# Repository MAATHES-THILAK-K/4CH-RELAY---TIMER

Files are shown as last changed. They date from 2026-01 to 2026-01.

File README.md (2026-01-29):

# 4CH Relay Timer

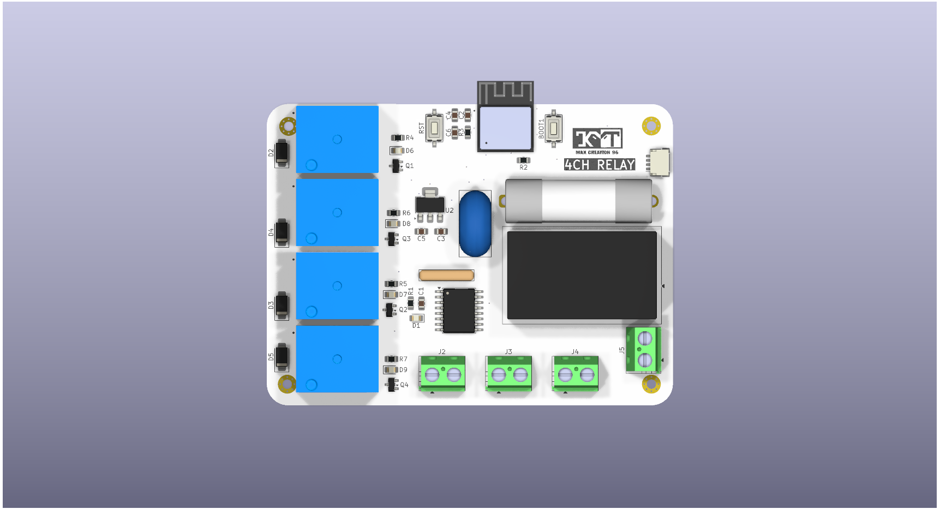
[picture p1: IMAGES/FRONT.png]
PCB


## Overview
ESP32-C3 based 4-channel relay controller with DS3231 RTC for timer applications. Each channel handles 10A AC loads with MOSFET input control.

## Features
- 4x 10A relays with MOSFET control
- ESP32-C3 Mini for Wi-Fi/Bluetooth
- DS3231 RTC for precise timing
- Direct AC input sensing
- Timer-based automation

## Hardware
- MCU: ESP32-C3-MINI-1
- RTC: DS3231 with battery backup
- Relays: 10A 250VAC SPDT
- Input: 5V DC
- AC sensing: Opto-isolated

## Usage
1. Power with 5V DC
2. Connect AC loads to relay outputs
3. Program via USB-C
4. Set timers via web interface

## Safety
⚠️ **HIGH VOLTAGE** - Requires proper insulation and qualified installation.

## License
Apache 2.0

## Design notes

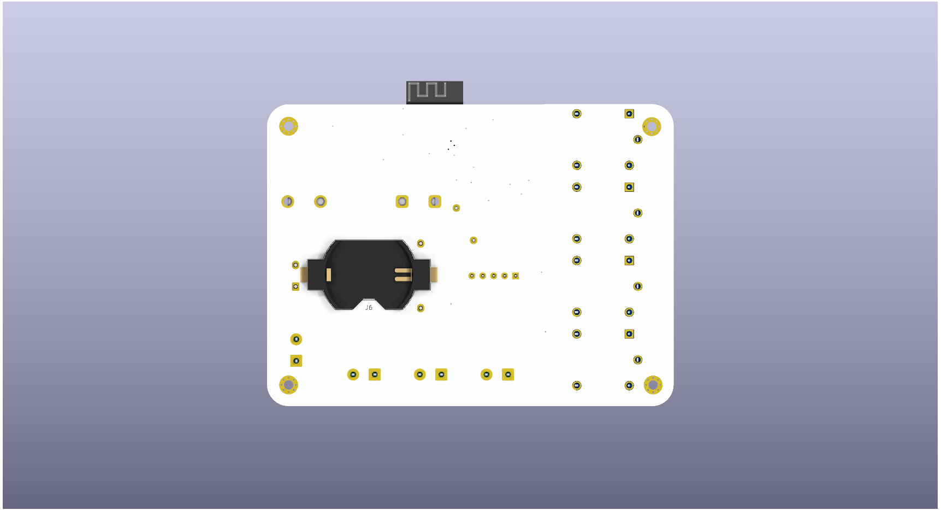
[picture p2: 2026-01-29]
IMAGES/BACK.png

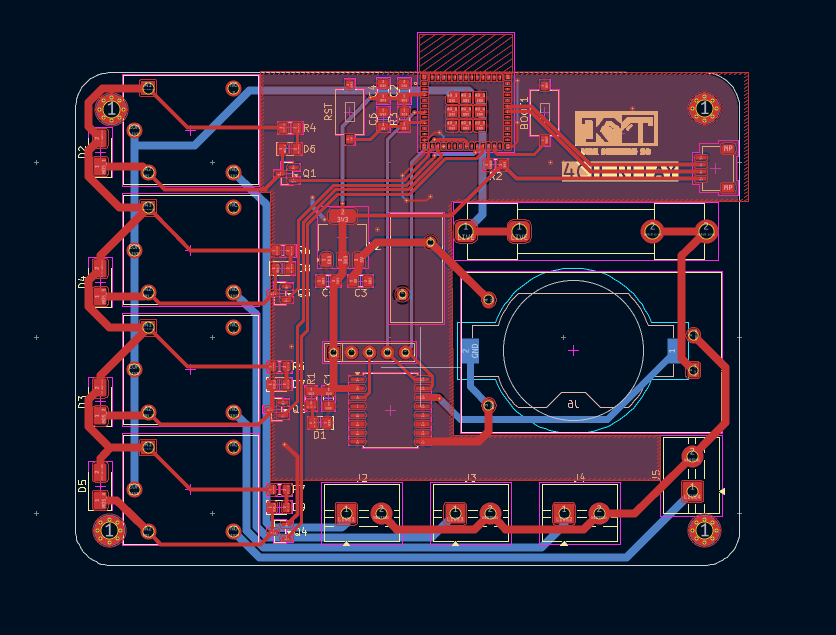
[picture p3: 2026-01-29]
IMAGES/Screenshot from 2026-01-29 18-53-19.png

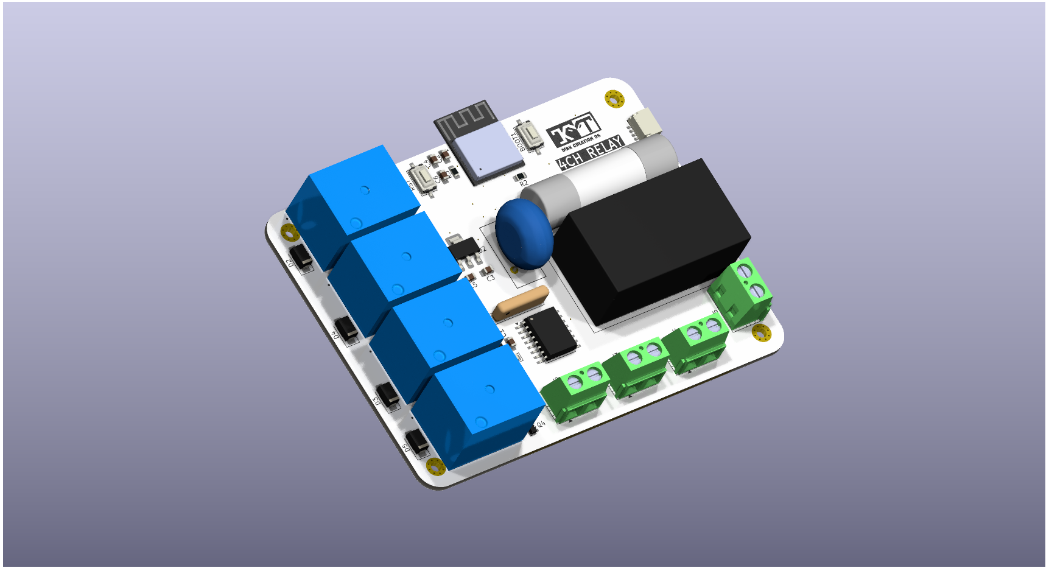
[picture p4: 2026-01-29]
IMAGES/ISOMETRIC.png

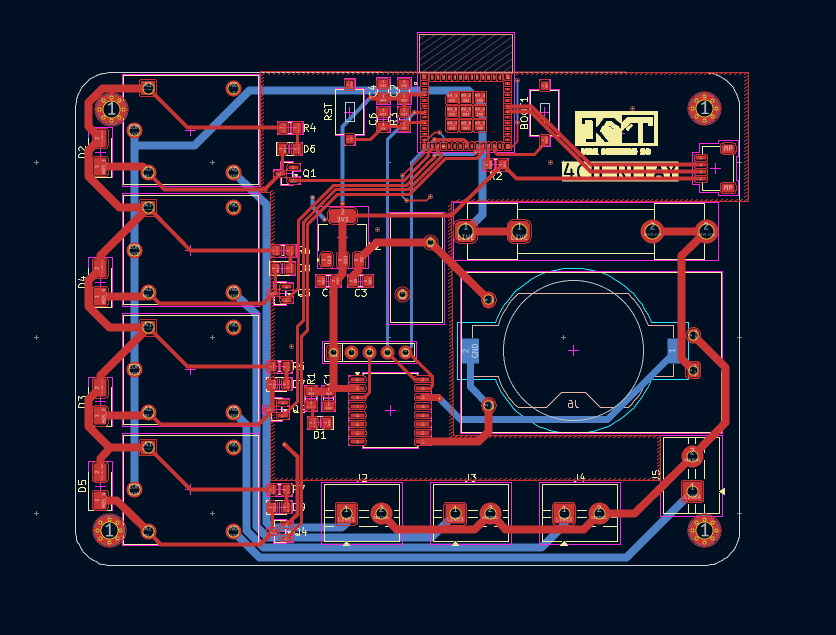
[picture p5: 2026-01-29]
IMAGES/Screenshot from 2026-01-29 18-53-23.png

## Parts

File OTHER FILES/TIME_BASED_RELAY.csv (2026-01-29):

Reference | Qty | Value | DNP | Exclude from BOM | Exclude from Board | Footprint | Datasheet
BOOT1,RST1 | 2 | SW_Push |  |  |  | Button_Switch_SMD:SW_Tactile_SPST_NO_Straight_CK_PTS636Sx25SMTRLFS | ~
C1,C4 | 2 | 0.1uF |  |  |  | Capacitor_SMD:C_0805_2012Metric_Pad1.18x1.45mm_HandSolder | ~
C2,C3,C5 | 3 | 10uF |  |  |  | Capacitor_SMD:C_0805_2012Metric_Pad1.18x1.45mm_HandSolder | ~
C6 | 1 | 1uF |  |  |  | Capacitor_SMD:C_0805_2012Metric_Pad1.18x1.45mm_HandSolder | ~
D1,D6,D7,D8,D9 | 5 | LED |  |  |  | LED_SMD:LED_0805_2012Metric_Pad1.15x1.40mm_HandSolder | ~
D2,D3,D4,D5 | 4 | SS14 |  |  |  | Diode_SMD:D_SMA | https://www.vishay.com/docs/88746/ss12.pdf
F1 | 1 | 250V@500mA |  |  |  | Fuse:Fuseholder_Clip-6.3x32mm_Littelfuse_102_122_Inline_P34.21x7.62mm_D1.98mm_Horizontal | ~
H1,H2,H3,H4 | 4 | MH |  | Excluded from BOM |  | MountingHole:MountingHole_2.2mm_M2_Pad_Via | ~
J1 | 1 | 01x04 |  |  |  | Connector_JST:JST_SH_SM04B-SRSS-TB_1x04-1MP_P1.00mm_Horizontal | ~
J2,J3,J4,J5 | 4 | 01x02 |  |  |  | TerminalBlock:TerminalBlock_MaiXu_MX126-5.0-02P_1x02_P5.00mm | ~
J6 | 1 | 01X02 |  |  |  | Battery:BatteryHolder_Keystone_1058_1x2032 | ~
K1,K2,K3,K4 | 4 | SRD-05VDC-SL-C |  |  |  | RELAY_5V:RELAY_SRD-05VDC-SL-C
PS1 | 1 | HLK-PM01 |  |  |  | Converter_ACDC:Converter_ACDC_Hi-Link_HLK-PMxx | https://h.hlktech.com/download/ACDC%E7%94%B5%E6%BA%90%E6%A8%A1%E5%9D%973W%E7%B3%BB%E5%88%97/1/%E6%B5%B7%E5%87%8C%E7%A7%913W%E7%B3%BB%E5%88%97%E7%94%B5%E6%BA%9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
Q1,Q2,Q3,Q4 | 4 | AO3400A |  |  |  | Package_TO_SOT_SMD:SOT-23 | http://www.aosmd.com/pdfs/datasheet/AO3400A.pdf
R1,R4,R5,R6,R7 | 5 | 1k |  |  |  | Resistor_SMD:R_0805_2012Metric_Pad1.20x1.40mm_HandSolder | ~
R2,R3 | 2 | 10k |  |  |  | Resistor_SMD:R_0805_2012Metric_Pad1.20x1.40mm_HandSolder | ~
RN1 | 1 | 4k7 |  |  |  | Resistor_THT:R_Array_SIP5 | http://www.vishay.com/docs/31509/csc.pdf
RV1 | 1 | 275V-14D |  |  |  | Varistor:RV_Disc_D15.5mm_W7.5mm_P7.5mm | ~
U1 | 1 | DS3231M |  |  |  | Package_SO:SOIC-16W_7.5x10.3mm_P1.27mm | http://datasheets.maximintegrated.com/en/ds/DS3231.pdf
U2 | 1 | AMS1117-3.3 |  |  |  | Package_TO_SOT_SMD:SOT-223-3_TabPin2 | http://www.advanced-monolithic.com/pdf/ds1117.pdf
U3 | 1 | ESP32-C3-MINI-1-N4 |  |  |  | ESP32_C3_MINI:XCVR_ESP32-C3-MINI-1-N4

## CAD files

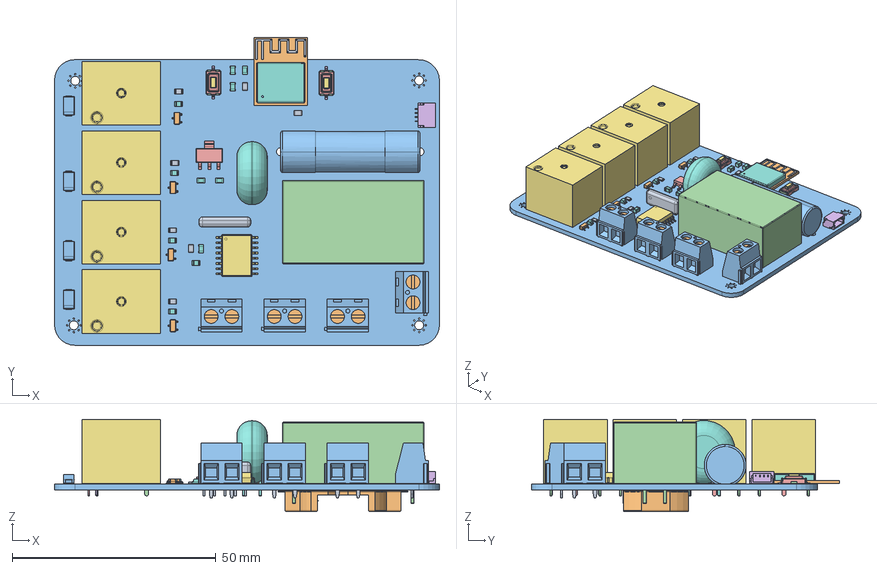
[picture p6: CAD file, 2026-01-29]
3D MODELS/TIME_BASED_RELAY.step
94.5 x 75.5 x 22.7 mm
R_0805_2012Metric x 7
SOT-23 x 4
BUSSMANN PV Fuse 10x38mm
SRD-05VDC-SL-C x 4
C_0805_2012Metric x 6
ESP32-C3-MINI-1-N4
D_SMA x 4
SW_Tactile_SPST_NO_Straight_CK_PTS636Sx25SMTRLFS x 2
LED_0805_2012Metric x 5
282837-2--3DModel-STEP-269445 x 4
Converter_ACDC_Hi-Link_HLK-PMxx
SOT-223
JST_SH_SM04B-SRSS-TB_1x04-1MP_P1.00mm_Horizontal
SOIC-16W_7.5x10.3mm_P1.27mm
RV_Disc_D15.5mm_W7.5mm_P7.5mm
R_Array_SIP5
BatteryHolder_Keystone_1058_1x2032
TIME_BASED_RELAY_PCB

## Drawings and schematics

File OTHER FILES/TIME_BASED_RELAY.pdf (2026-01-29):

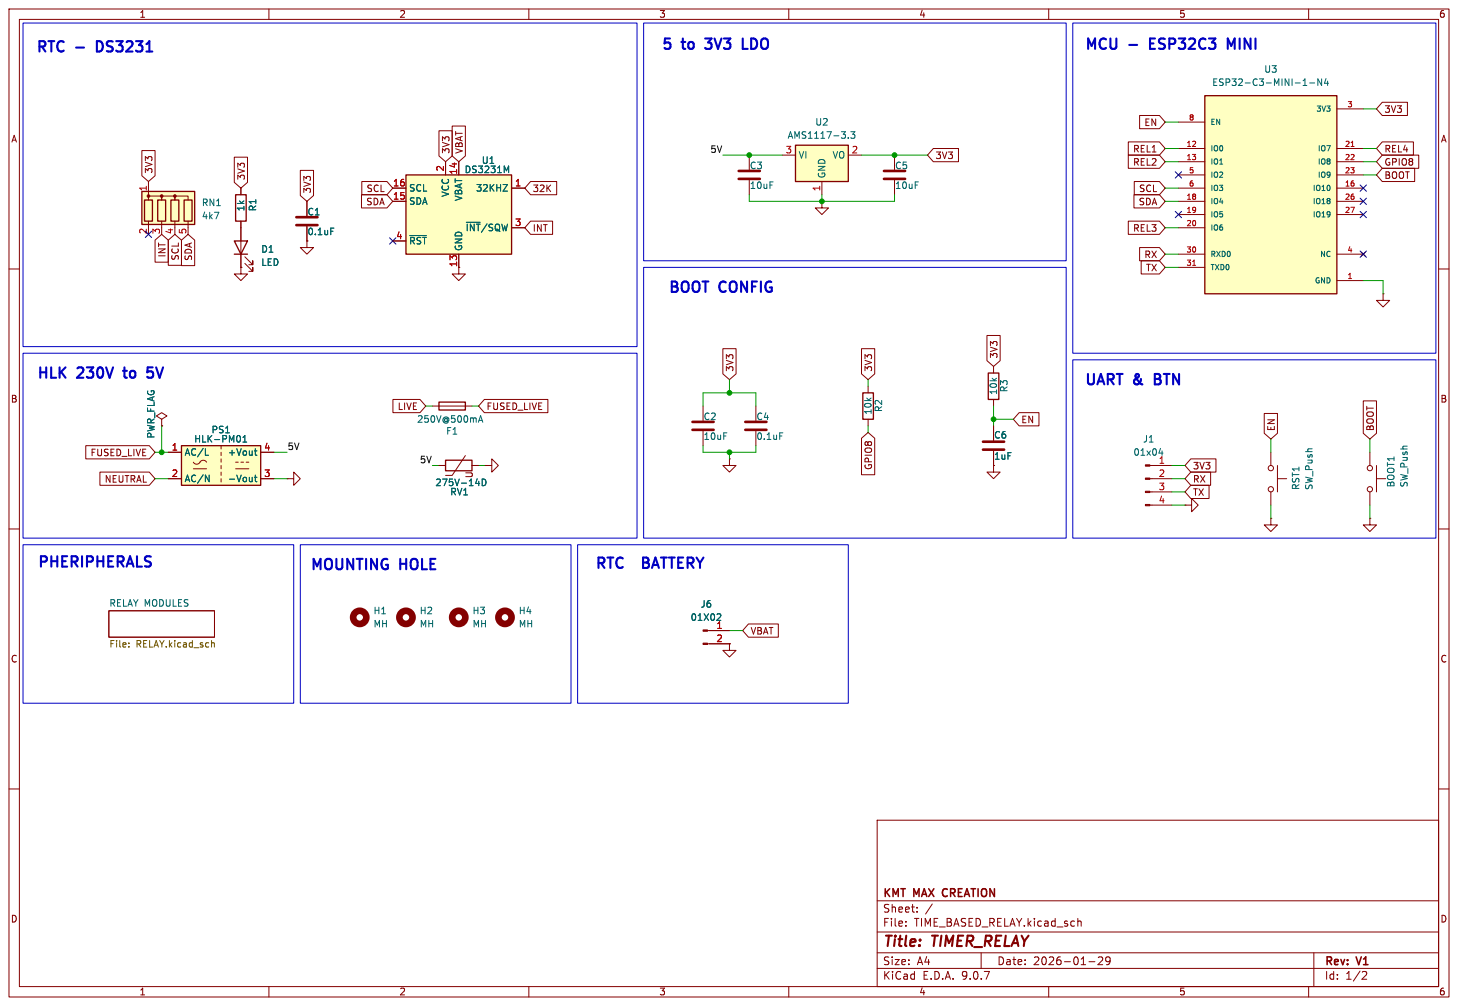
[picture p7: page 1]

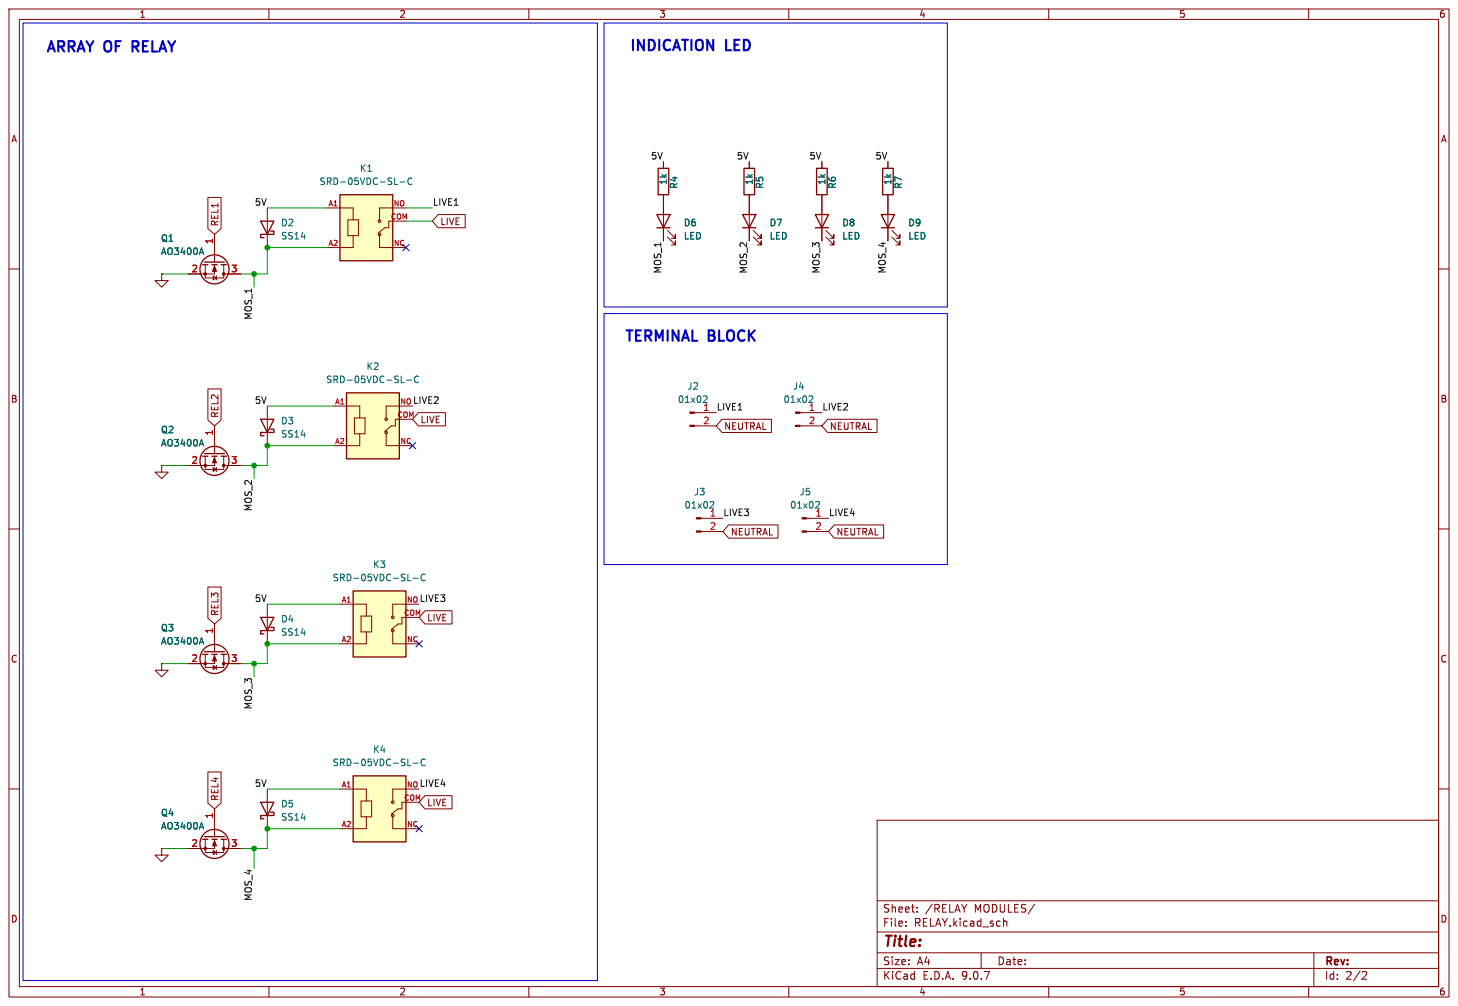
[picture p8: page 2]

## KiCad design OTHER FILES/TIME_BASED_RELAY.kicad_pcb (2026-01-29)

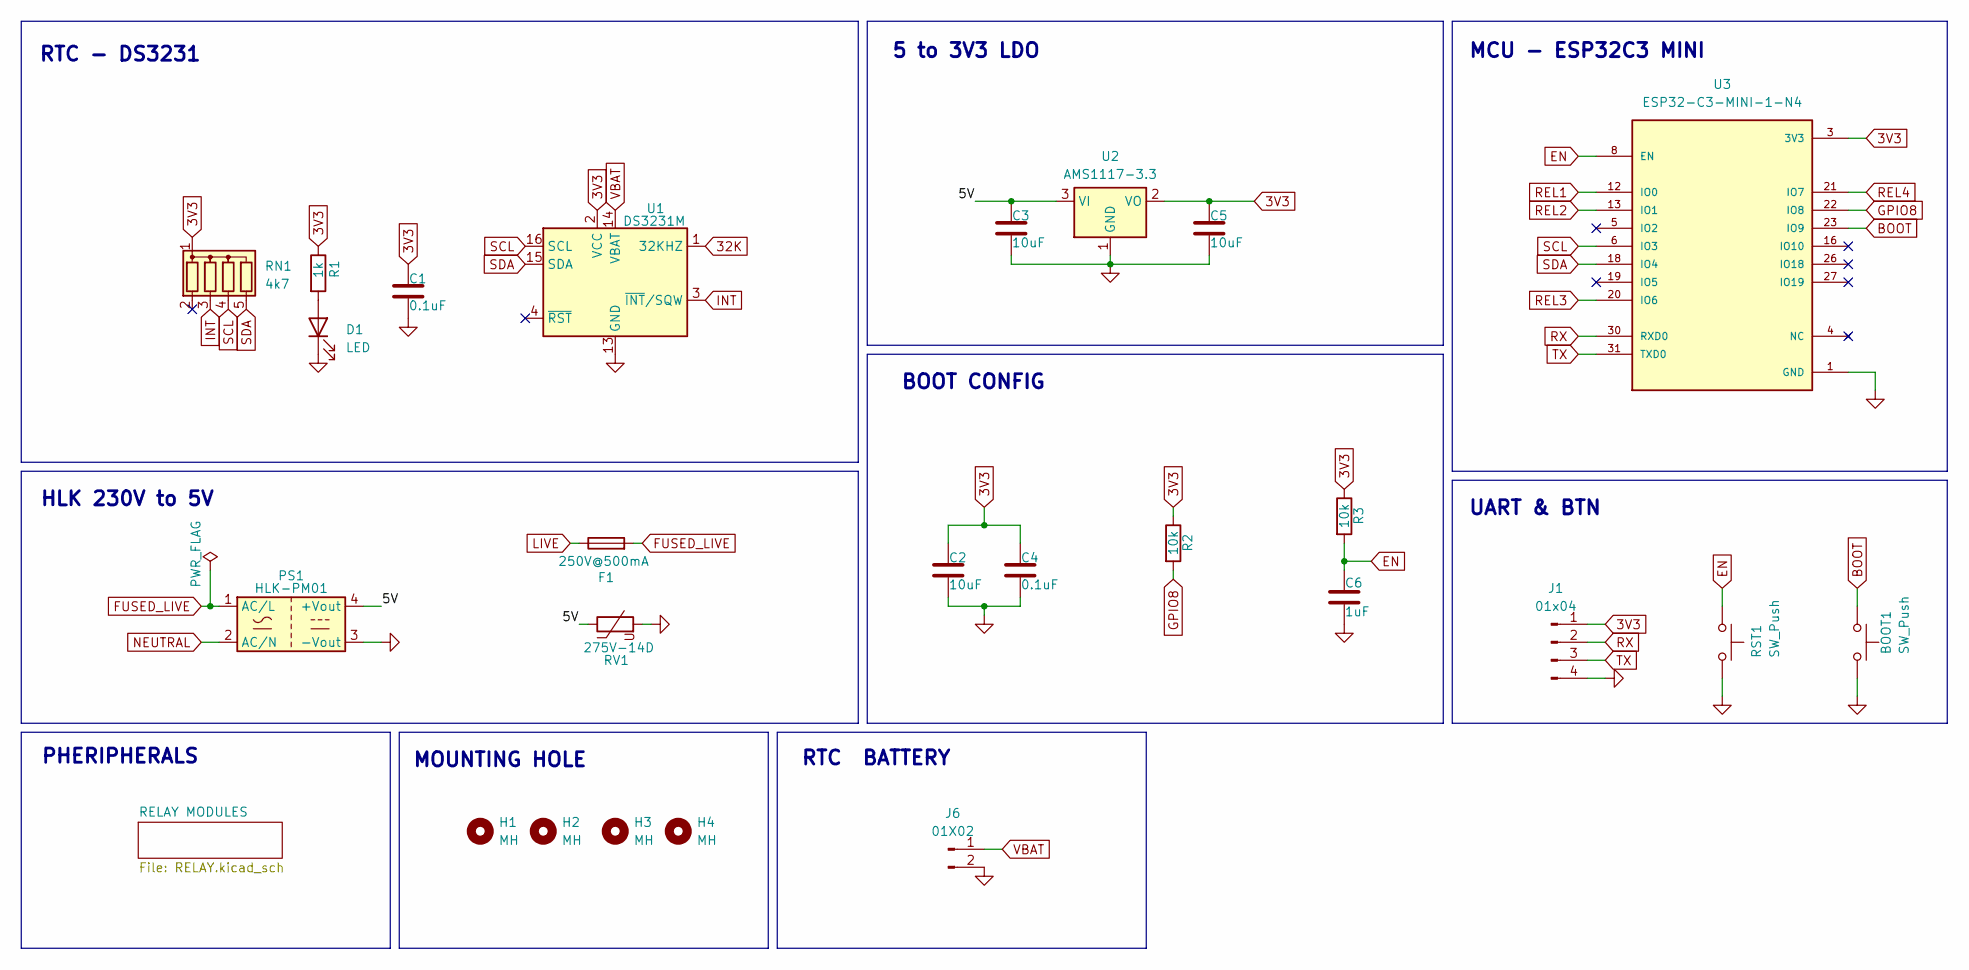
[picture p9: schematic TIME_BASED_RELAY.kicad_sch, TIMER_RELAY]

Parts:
BOOT1: SW_Push; SW_Tactile_SPST_NO_Straight_CK_PTS636Sx25SMTRLFS
C1, C4: 0.1uF; C_0805_2012Metric_Pad1.18x1.45mm_HandSolder
C2, C3, C5: 10uF; C_0805_2012Metric_Pad1.18x1.45mm_HandSolder
C6: 1uF; C_0805_2012Metric_Pad1.18x1.45mm_HandSolder
D1: LED; LED_0805_2012Metric_Pad1.15x1.40mm_HandSolder
F1: 250V@500mA; Fuseholder_Clip-6.3x32mm_Littelfuse_102_122_Inline_P34.21x7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
H1, H2, H3, H4: MH; MountingHole_2.2mm_M2_Pad_Via
J1: 01x04; JST_SH_SM04B-SRSS-TB_1x04-1MP_P1.00mm_Horizontal
J6: 01X02; BatteryHolder_Keystone_1058_1x2032
PS1: HLK-PM01; Converter_ACDC_Hi-Link_HLK-PMxx
R1: 1k; R_0805_2012Metric_Pad1.20x1.40mm_HandSolder
R2, R3: 10k; R_0805_2012Metric_Pad1.20x1.40mm_HandSolder
RN1: 4k7; R_Array_SIP5
RST1: SW_Push; SW_Tactile_SPST_NO_Straight_CK_PTS636Sx25SMTRLFS
RV1: 275V-14D; RV_Disc_D15.5mm_W7.5mm_P7.5mm
U1: DS3231M; SOIC-16W_7.5x10.3mm_P1.27mm
U2: AMS1117-3.3; SOT-223-3_TabPin2
U3: ESP32-C3-MINI-1-N4; XCVR_ESP32-C3-MINI-1-N4; PARTREV v1.0

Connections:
3V3: C1.1, C2.1, C4.1, C5.1, J1.1, R1.1, R2.1, R3.1, RN1.1 (common), U1.2 (VCC), U2.2 (VO), U3.3 (3V3)
32K: U1.1 (32KHZ)
/5V: C3.1, PS1.4 (+Vout), RV1.1, U2.3 (VI)
BOOT: BOOT1.1, U3.23 (IO9)
EN: C6.1, R3.2, RST1.1, U3.8 (EN); also elsewhere on the board
FUSED_LIVE: F1.2, PS1.1 (AC/L)
GND: BOOT1.2, C1.2, C2.2, C3.2, C4.2, C5.2, C6.2, D1.1 (K), J1.4, J6.2, PS1.3 (-Vout), RST1.2, RV1.2, U1.5 (GND), U1.6 (GND), U1.7 (GND), U1.8 (GND), U1.9 (GND), U1.10 (GND), U1.11 (GND), U1.12 (GND), U1.13 (GND), U2.1 (GND), U3.1 (GND), U3.2 (GND), U3.11 (GND), U3.14 (GND), U3.36 (GND), U3.37 (GND), U3.38 (GND), U3.39 (GND), U3.40 (GND), U3.41 (GND), U3.42 (GND), U3.43 (GND), U3.44 (GND), U3.45 (GND), U3.46 (GND), U3.47 (GND), U3.48 (GND), U3.49_1 (GND), U3.49_2 (GND), U3.49_3 (GND), U3.49_4 (GND), U3.49_5 (GND), U3.49_6 (GND), U3.49_7 (GND), U3.49_8 (GND), U3.49_9 (GND), U3.50 (GND), U3.51 (GND), U3.52 (GND), U3.53 (GND); also elsewhere on the board
GPIO8: R2.2, U3.22 (IO8)
INT: RN1.3 (R2), U1.3 (~INT/SQW)
LIVE: F1.1; also elsewhere on the board
NEUTRAL: PS1.2 (AC/N); also elsewhere on the board
unnamed: D1.2 (A), R1.2
REL1: U3.12 (IO0); also elsewhere on the board
REL2: U3.13 (IO1); also elsewhere on the board
REL3: U3.20 (IO6); also elsewhere on the board
REL4: U3.21 (IO7); also elsewhere on the board
RX: J1.2, U3.30 (RXD0)
SCL: RN1.4 (R3), U1.16 (SCL), U3.6 (IO3)
SDA: RN1.5 (R4), U1.15 (SDA), U3.18 (IO4)
TX: J1.3, U3.31 (TXD0)
VBAT: J6.1, U1.14 (VBAT)

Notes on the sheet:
PHERIPHERALS
HLK 230V to 5V
RTC BATTERY
MOUNTING HOLE
UART & BTN
BOOT CONFIG
MCU - ESP32C3 MINI
RTC - DS3231
5 to 3V3 LDO

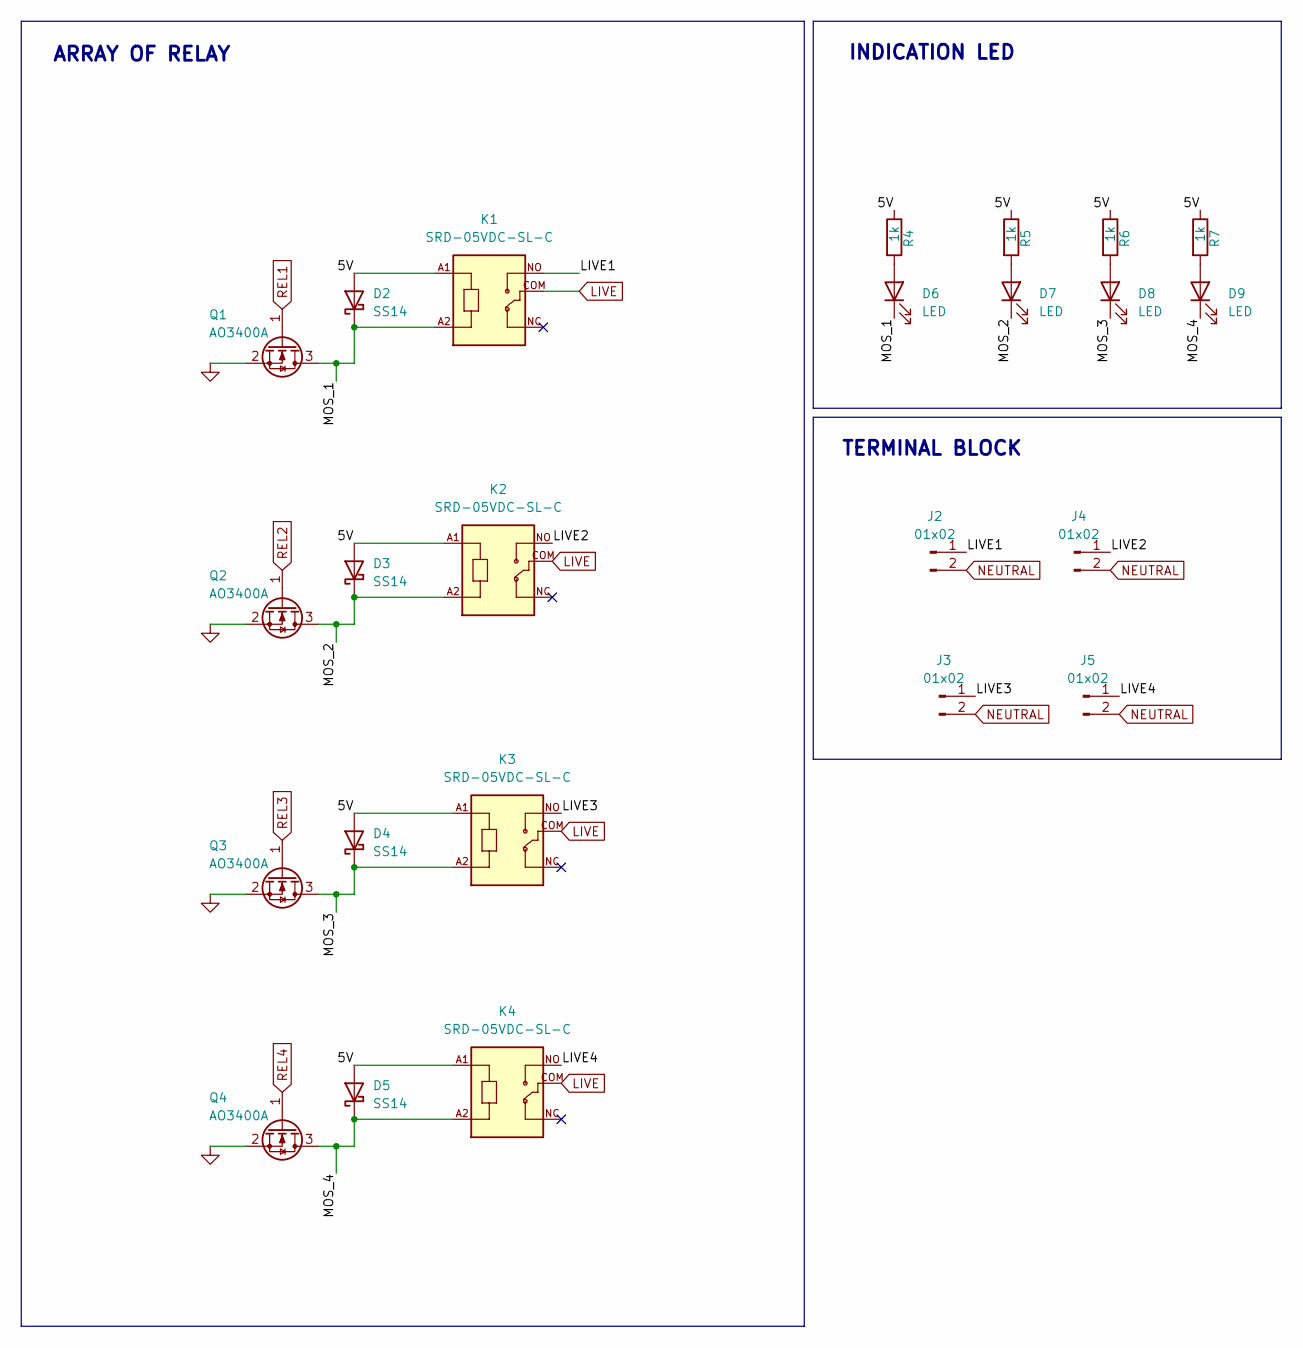
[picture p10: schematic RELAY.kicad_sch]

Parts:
D2, D3, D4, D5: SS14; D_SMA
D6, D7, D8, D9: LED; LED_0805_2012Metric_Pad1.15x1.40mm_HandSolder
J2, J3, J4, J5: 01x02; TerminalBlock_MaiXu_MX126-5.0-02P_1x02_P5.00mm
K1, K2, K3, K4: SRD-05VDC-SL-C; RELAY_SRD-05VDC-SL-C
Q1, Q2, Q3, Q4: AO3400A; SOT-23
R4, R5, R6, R7: 1k; R_0805_2012Metric_Pad1.20x1.40mm_HandSolder

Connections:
/RELAY MODULES/5V: D2.2 (A), D3.2 (A), D4.2 (A), D5.2 (A), K1.A1, K2.A1, K3.A1, K4.A1, R4.1, R5.1, R6.1, R7.1
/RELAY MODULES/LIVE1: J2.1, K1.NO
/RELAY MODULES/LIVE2: J4.1, K2.NO
/RELAY MODULES/LIVE3: J3.1, K3.NO
/RELAY MODULES/LIVE4: J5.1, K4.NO
/RELAY MODULES/MOS_1: D2.1 (K), D6.1 (K), K1.A2, Q1.3 (D)
/RELAY MODULES/MOS_2: D3.1 (K), D7.1 (K), K2.A2, Q2.3 (D)
/RELAY MODULES/MOS_3: D4.1 (K), D8.1 (K), K3.A2, Q3.3 (D)
/RELAY MODULES/MOS_4: D5.1 (K), D9.1 (K), K4.A2, Q4.3 (D)
GND: Q1.2 (S), Q2.2 (S), Q3.2 (S), Q4.2 (S); also elsewhere on the board
LIVE: K1.COM, K2.COM, K3.COM, K4.COM; also elsewhere on the board
NEUTRAL: J2.2, J3.2, J4.2, J5.2; also elsewhere on the board
unnamed: D6.2 (A), R4.2
unnamed: D7.2 (A), R5.2
unnamed: D8.2 (A), R6.2
unnamed: D9.2 (A), R7.2
REL1: Q1.1 (G); also elsewhere on the board
REL2: Q2.1 (G); also elsewhere on the board
REL3: Q3.1 (G); also elsewhere on the board
REL4: Q4.1 (G); also elsewhere on the board

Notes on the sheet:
ARRAY OF RELAY
INDICATION LED
TERMINAL BLOCK

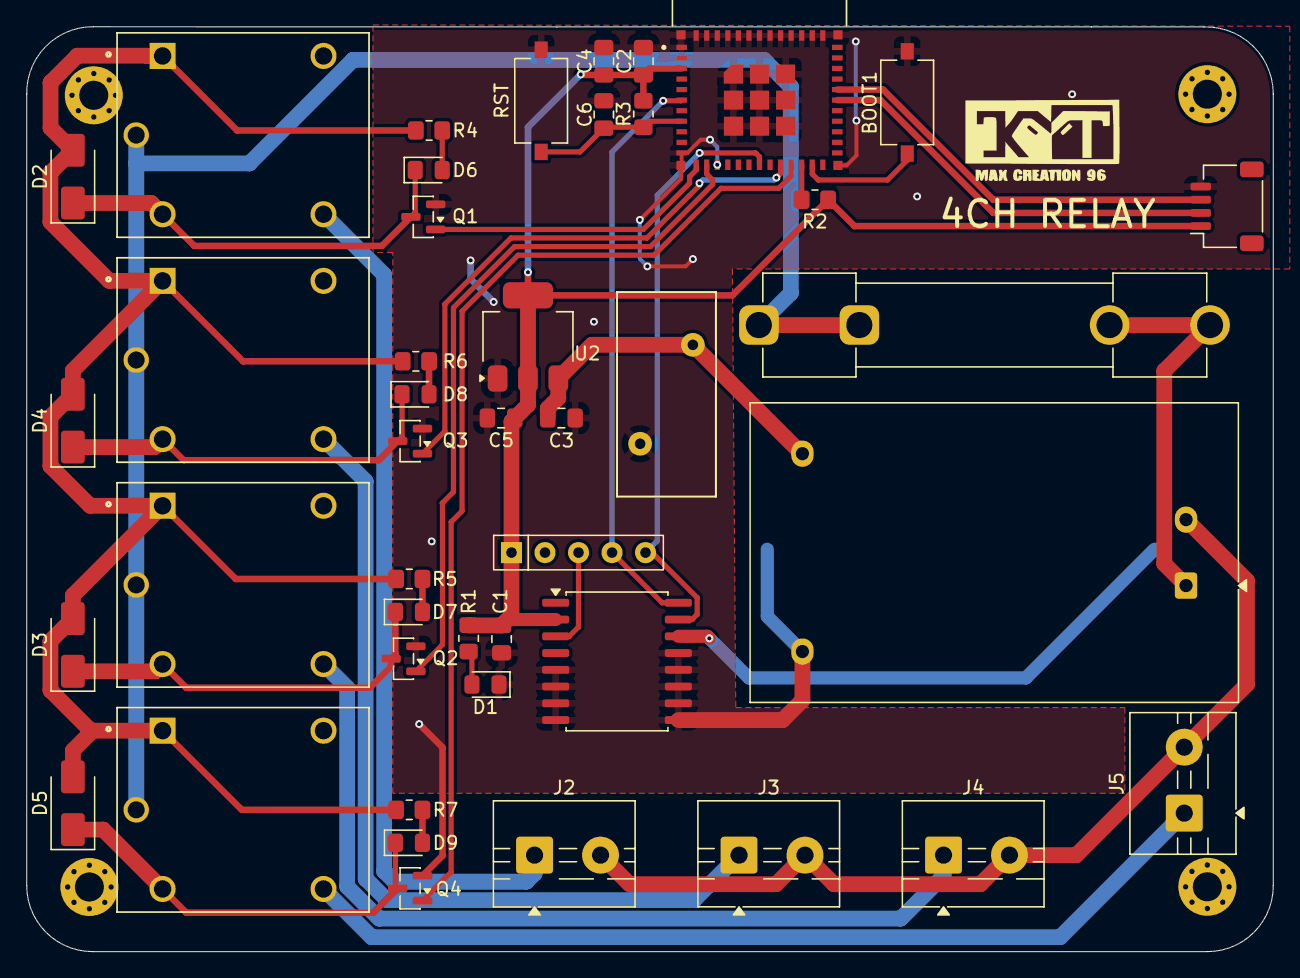
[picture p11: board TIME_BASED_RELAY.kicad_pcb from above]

Board: 2 copper layers, 94.5 x 70.1 mm, 49 parts (1 on the bottom side), 33 nets.

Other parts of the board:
RST: SW_Push; SW_Tactile_SPST_NO_Straight_CK_PTS636Sx25SMTRLFS

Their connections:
EN: RST.1; also elsewhere on the board
GND: RST.2; also elsewhere on the board
